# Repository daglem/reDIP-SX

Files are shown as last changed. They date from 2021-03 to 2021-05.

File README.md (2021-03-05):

# reDIP SX

## ESP32 / iCE40UP5K / SGTL5000 development board with MOS 6581/8580 SID pinout
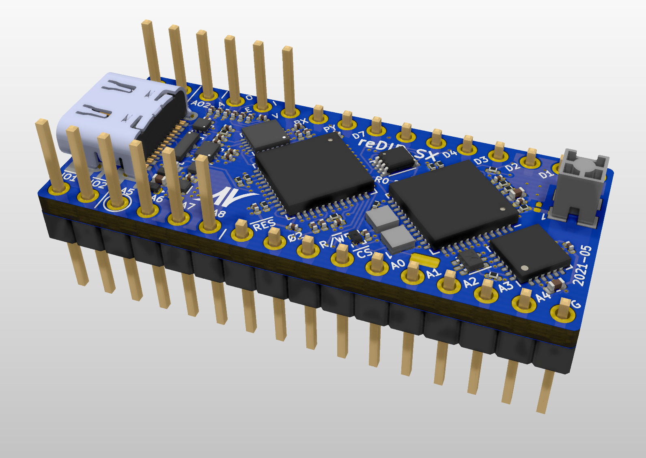
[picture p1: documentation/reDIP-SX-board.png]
Board


## Overview
The reDIP SX is an open source hardware development board which combines the following in a DIP-32 size package:

* Espressif ESP32-PICO-V3-02 MCU with Wi-Fi and Bluetooth
* Lattice iCE40UP5K FPGA
* NXP SGTL5000 Audio Codec
* 64Mbit PSRAM
* Two RGB LEDs
* USB-C receptacle for power, serial communication, and analog audio
* 5V tolerant I/O

In short, a lot of fun stuff is crammed onto a small board!

For a more purist FPGA platform for MOS 6581/8580 SID emulation, you need look no further than the [reDIP SID](https://github.com/daglem/reDIP-SID)!

## General use

### I/O interfaces

#### Header pins:

* 5V input
* 3.3V output
* 22 FPGA GPIO
* 3 FPGA current drive / open-drain I/O
* 4 audio pins (stereo line input, stereo headphone output)
* GND

All FPGA I/O is 5V tolerant, and can drive 5V TTL. JP1 can be shorted to make the 5V input pin bidirectional, e.g. to power 5V TTL devices.

The number of FPGA I/O is sufficient for e.g. three twelve-pin PMOD interfaces (with two pins open-drain or input-only).

#### Solder pads:

* Stereo line output (left, right, GND)
* RGB LED strip data
* ESP32 IO25
* ESP32 I35

#### USB-C functions:

* 5V power
* Serial interface (CP2102N to ESP32)
* Microphone input / stereo headphone output (Audio Accessory Mode)

### Internal interconnect buses

The board has three internal interconnect buses with the following ICs attached:

* SPI (Serial Peripheral Interface)
  * ESP32 MCU
  * iCE40UP5K FPGA
  * PSRAM
* I²S (Inter-IC sound)
  * ESP32 MCU
  * iCE40UP5K FPGA
  * SGTL5000 Audio Codec
* I²C (Inter-Integrated Circuit)
  * ESP32 MCU
  * iCE40UP5K FPGA
  * SGTL5000 Audio Codec

The MCU and the FPGA can communicate via the SPI bus, and they can both access the PSRAM. The FPGA is initially configured by the MCU via the SPI bus.

Both the MCU and the FPGA can act as either master or slave on the I²S bus. E.g. if the FPGA acts as the I²S master, both the audio codec and the MCU can in theory play back audio, the latter over Wi-Fi or Bluetooth.

Both the MCU and the FPGA can configure the audio codec via the I²C bus.

## MOS 6581/8580 SID compatibility

It just so happens that the board is mostly pin compatible with the venerable MOS 6581/8580 SID sound chip :wink:

For anyone wanting to experiment with a SID setup, while avoiding blown fuses, damaged sockets, and release of magic smoke:

* A 2A C64 power supply is recommended
* Make sure that JP1 is open
* Carefully follow the instructions in the [schematic diagram](documentation/reDIP-SX-sch.pdf) for making a socket adapter

## Disclaimer

Please note that this is my very first board - rookie mistakes are probably made, and [feedback](https://github.com/daglem/reDIP-SX/discussions/1) is welcome. The board has not been manufactured yet, and is thus completely untested.

## Board Front
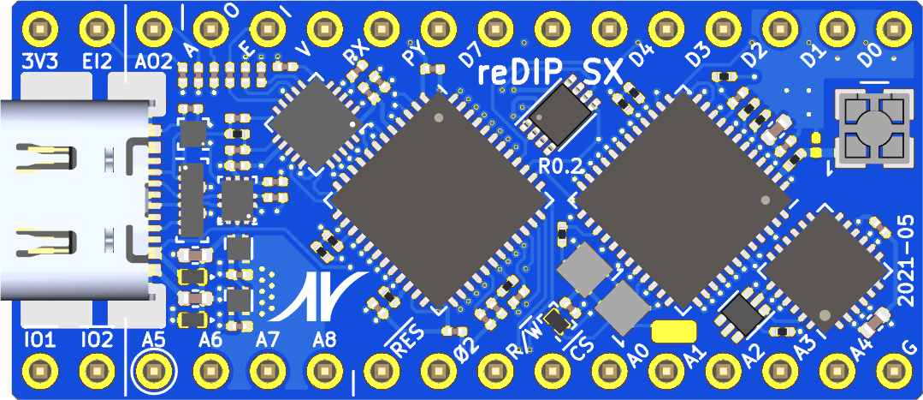
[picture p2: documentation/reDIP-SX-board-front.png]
Board Front


## Board Back
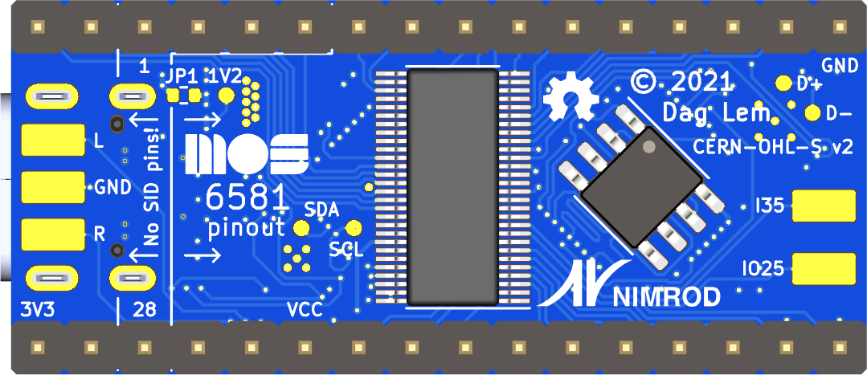
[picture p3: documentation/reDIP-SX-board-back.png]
Board Back


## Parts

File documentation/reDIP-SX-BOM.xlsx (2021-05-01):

Prj: | reDIP SX |  |  |  |  |  |  | Board Qty: | 100
Co.: | Nimrod |  |  |  |  |  |  | Unit Cost: | $0.00
Prj date: | lø. 01. mai 2021 kl. 22.55 +0200 |  |  |  |  |  |  | Total Cost: | $0.00 |  |  |  | $0.00 | 0 |  |  |  | $0.00 | 0 |  |  |  | $0.00 | 0 |  |  |  | $0.00 | 0 |  |  |  | $0.00 | 0 |  |  |  | $0.00 | 0 |  |  |  | $0.00 | 0 |  |  |  | $0.00 | 0
$ date: | 2021-05-01 22:55:19
Global Part Info |  |  |  |  |  |  |  |  |  | Arrow |  |  |  |  | Digi-Key |  |  |  |  | Farnell |  |  |  |  | LCSC |  |  |  |  | Mouser |  |  |  |  | Newark |  |  |  |  | RS Components |  |  |  |  | TME
Refs | Value | Desc | Notes | Footprint | Manf | Manf# | Qty | Unit$ | Ext$ | Avail | Purch | Unit$ | Ext$ | Cat# | Avail | Purch | Unit$ | Ext$ | Cat# | Avail | Purch | Unit$ | Ext$ | Cat# | Avail | Purch | Unit$ | Ext$ | Cat# | Avail | Purch | Unit$ | Ext$ | Cat# | Avail | Purch | Unit$ | Ext$ | Cat# | Avail | Purch | Unit$ | Ext$ | Cat# | Avail | Purch | Unit$ | Ext$ | Cat#
AE1 | 47948-0001 | ANTENNA MID CHIP |  | Molex_47948-0001 | Molex | 47948-0001 (https://www.molex.com/molex/products/part-detail/antennas/0479480001) | 0 | $0.00 | $0.00 |  |  |  |  |  | NonStk |  | $0.00 | $0.00 | WM4893CT-ND (https://octopart.com/click/track?c=1&ai=8078&sig=090b9de&sid=459&ppid=20326346&vpid=114393393&ct=offers) | 14432 |  | $0.00 | $0.00 | 3498912RL (https://octopart.com/click/track?ai=8078&sig=087403b&sid=819&ppid=20326346&vpid=632629437&ct=offers) |  |  |  |  |  | NonStk |  | $0.00 | $0.00 | 538479480001 (https://octopart.com/click/track?c=1&ai=8078&sig=0951079&sid=2401&ppid=20326346&vpid=40439801&ct=offers) | 13470 |  | $0.00 | $0.00 | 64T4821 (https://octopart.com/click/track?ai=8078&sig=0ce4145&sid=2402&ppid=20326346&vpid=503304515&ct=offers) | 8762 |  | $0.00 | $0.00 | 7595325 (https://octopart.com/click/track?ai=8078&sig=090870c&sid=10022&ppid=20326346&vpid=199068433&ct=offers) | NonStk |  | $0.00 | $0.00 | 479480001 (https://octopart.com/click/track?ai=8078&sig=0f9b69c&sid=1532&ppid=20326346&vpid=709093263&ct=offers)
C1,C3 | 1uF | CAP CER 2.2uF 16V 10% X6S 0402 | 5V DC DERATED TO 1uF | C_0402_1005Metric | Murata | GRM155C81C225KE11D (https://www.murata.com/products/productdetail.aspx?partno=GRM155C81C225KE11D) | 0 | $0.00 | $0.00 |  |  |  |  |  | NonStk |  | $0.00 | $0.00 | 490-14595-1-ND (https://octopart.com/click/track?c=1&ai=8078&sig=0de3de3&sid=459&ppid=46692789&vpid=410305221&ct=offers) | 9990 |  | $0.00 | $0.00 | 3581345 (https://octopart.com/click/track?ai=8078&sig=0d8f33b&sid=11744&ppid=46692789&vpid=667012154&ct=offers) | 3280 |  | $0.00 | $0.00 | C437523 (https://octopart.com/click/track?ai=8078&sig=005ea9f&sid=27971&ppid=46692789&vpid=666930444&ct=offers) | NonStk |  | $0.00 | $0.00 | 81GRM155C81C225KE1D (https://octopart.com/click/track?c=1&ai=8078&sig=06521e3&sid=2401&ppid=46692789&vpid=230758256&ct=offers) | 9990 |  | $0.00 | $0.00 | 92AH5000 (https://octopart.com/click/track?ai=8078&sig=0849c23&sid=2402&ppid=46692789&vpid=669036303&ct=offers)
C2,C11-C14,C18-C22,C24,C28 | 1uF | CAP CER 1uF 6.3V 20% X6S 0201 | C11-C14,C18-C22: 1.55V DC AUDIO C2,C24,C28: 1.2V DC | C_0201_0603Metric | Murata | GRM033C80J105ME05D (https://www.murata.com/products/productdetail.aspx?partno=GRM033C80J105ME05D) | 0 | $0.00 | $0.00 |  |  |  |  |  | NonStk |  | $0.00 | $0.00 | 490-13218-1-ND (https://octopart.com/click/track?c=1&ai=8078&sig=07524e2&sid=459&ppid=71220979&vpid=252726184&ct=offers) | 30000 |  | $0.00 | $0.00 | 3582762 (https://octopart.com/click/track?c=1&ai=8078&sig=013a2f0&sid=819&ppid=71220979&vpid=670691828&ct=offers) | 3440 |  | $0.00 | $0.00 | C385023 (https://octopart.com/click/track?ai=8078&sig=05d4785&sid=27971&ppid=71220979&vpid=552547217&ct=offers) |  |  |  |  |  | 30000 |  | $0.00 | $0.00 | 03AJ1531 (https://octopart.com/click/track?c=1&ai=8078&sig=0e14f17&sid=2402&ppid=71220979&vpid=671481163&ct=offers)
C4 | 1uF | CAP CER 4.7uF 6.3V 20% X5R 0201 | 3.3V DC DERATED TO 1uF | C_0201_0603Metric | Murata | GRM035R60J475ME15D (https://www.murata.com/products/productdetail.aspx?partno=GRM035R60J475ME15D) | 0 | $0.00 | $0.00 |  |  |  |  |  | 903983 |  | $0.00 | $0.00 | 490-13230-1-ND (https://octopart.com/click/track?ai=8078&sig=02d1bd9&sid=459&ppid=67141176&vpid=252726416&ct=offers) | 50000 |  | $0.00 | $0.00 | 3238402 (https://octopart.com/click/track?ai=8078&sig=087aedd&sid=11744&ppid=67141176&vpid=585909672&ct=offers) | 180195 |  | $0.00 | $0.00 | C335103 (https://octopart.com/click/track?ai=8078&sig=0ec1763&sid=27971&ppid=67141176&vpid=510777411&ct=offers) | 155342 |  | $0.00 | $0.00 | 81GRM035R60J475ME5D (https://octopart.com/click/track?ai=8078&sig=0e8e022&sid=2401&ppid=67141176&vpid=262254328&ct=offers) | 50000 |  | $0.00 | $0.00 | 34AH0743 (https://octopart.com/click/track?ai=8078&sig=02cfcbc&sid=2402&ppid=67141176&vpid=587966703&ct=offers)
C5,C17 | 10uF | CAP CER 10uF 6.3V 20% X5R 0402 | 3.3V DC | C_0402_1005Metric | Murata | GRM155R60J106ME15D (https://www.murata.com/products/productdetail.aspx?partno=GRM155R60J106ME15D) | 0 | $0.00 | $0.00 |  |  |  |  |  | 3743048 |  | $0.00 | $0.00 | 490-13238-1-ND (https://octopart.com/click/track?ai=8078&sig=018ad6b&sid=459&ppid=71220998&vpid=252726526&ct=offers) | 140000 |  | $0.00 | $0.00 | 3582794 (https://octopart.com/click/track?c=1&ai=8078&sig=0115312&sid=819&ppid=71220998&vpid=670691894&ct=offers) | 2990 |  | $0.00 | $0.00 | C412251 (https://octopart.com/click/track?ai=8078&sig=0543bf4&sid=27971&ppid=71220998&vpid=582946846&ct=offers) | 1634310 |  | $0.00 | $0.00 | 81GRM155R60J106ME5D (https://octopart.com/click/track?ai=8078&sig=0b273d0&sid=2401&ppid=71220998&vpid=259388278&ct=offers) | 150000 |  | $0.00 | $0.00 | 03AJ1576 (https://octopart.com/click/track?c=1&ai=8078&sig=0c372ee&sid=2402&ppid=71220998&vpid=671481195&ct=offers)
C6-C10,C15,C16,C23,C25-C27,C29-C32 | 0.1uF | CAP CER 0.22uF 6.3V 20% X5R 0201 | C6-C9,C16,C23,C25-C27,C29-C32: 3.3V DC DERATED TO 0.1uF C10,C15: 1.55V DC AUDIO DERATED TO 0.1uF | C_0201_0603Metric | Murata | GRM033R60J224KE15D (https://www.murata.com/products/productdetail.aspx?partno=GRM033R60J224KE15D) | 0 | $0.00 | $0.00 |  |  |  |  |  | 2181765 |  | $0.00 | $0.00 | 490-10406-1-ND (https://octopart.com/click/track?ai=8078&sig=0492ec2&sid=459&ppid=51454422&vpid=172161550&ct=offers) | 120000 |  | $0.00 | $0.00 | 2990684 (https://octopart.com/click/track?ai=8078&sig=0efc20f&sid=819&ppid=51454422&vpid=528007216&ct=offers) | 20800 |  | $0.00 | $0.00 | C76931 (https://octopart.com/click/track?ai=8078&sig=0f2788c&sid=27971&ppid=51454422&vpid=445986847&ct=offers) | 301000 |  | $0.00 | $0.00 | 81GRM33R60J224KE15D (https://octopart.com/click/track?ai=8078&sig=0207666&sid=2401&ppid=51454422&vpid=178169497&ct=offers) | 120000 |  | $0.00 | $0.00 | 94AC8892 (https://octopart.com/click/track?ai=8078&sig=0d37eed&sid=2402&ppid=51454422&vpid=529126546&ct=offers) | 7000 |  | $0.00 | $0.00 | 1851581 (https://octopart.com/click/track?ai=8078&sig=0eaea66&sid=10022&ppid=51454422&vpid=562632808&ct=offers)
D1,D2 | PMEG2010BELD | DIODE SCHOTTKY 20V 1A LOW VF SOD882D |  | D_SOD-882D | Nexperia | PMEG2010BELD,315 (https://assets.nexperia.com/documents/data-sheet/PMEG2010BELD.pdf) | 0 | $0.00 | $0.00 |  |  |  |  |  | 32181 |  | $0.00 | $0.00 | 1727-1084-1-ND (https://octopart.com/click/track?ai=8078&sig=05f022d&sid=459&ppid=78741408&vpid=417205872&ct=offers) | NonStk |  | $0.00 | $0.00 | 2191801 (https://octopart.com/click/track?c=1&ai=8078&sig=0ee080b&sid=819&ppid=78741408&vpid=521253387&ct=offers) |  |  |  |  |  | 249 |  | $0.00 | $0.00 | 771PMEG2010BELD,315 (https://octopart.com/click/track?ai=8078&sig=077655c&sid=2401&ppid=78741408&vpid=416182007&ct=offers) | NonStk |  | $0.00 | $0.00 | 55W4407 (https://octopart.com/click/track?c=1&ai=8078&sig=03a6e2e&sid=2402&ppid=78741408&vpid=511382518&ct=offers)
D3 | ESD7016 | IC ESD PROTECTION UDFN-8 |  | 517CB-3.3x1.0mm_P0.4mm | ON Semiconductor | ESD7016MUTAG (https://www.onsemi.com/pub/Collateral/ESD7016-D.PDF) | 0 | $0.00 | $0.00 |  |  |  |  |  | 23415 |  | $0.00 | $0.00 | ESD7016MUTAGOSCT-ND (https://octopart.com/click/track?ai=8078&sig=0f2b3ec&sid=459&ppid=25645602&vpid=210238806&ct=offers) | 10184 |  | $0.00 | $0.00 | 2535917 (https://octopart.com/click/track?ai=8078&sig=01a9746&sid=11744&ppid=25645602&vpid=260636544&ct=offers) | 3073 |  | $0.00 | $0.00 | C463227 (https://octopart.com/click/track?ai=8078&sig=0d3fc6a&sid=27971&ppid=25645602&vpid=609441157&ct=offers) | 631 |  | $0.00 | $0.00 | 863ESD7016MUTAG (https://octopart.com/click/track?ai=8078&sig=0b9599e&sid=2401&ppid=25645602&vpid=93676548&ct=offers) | 442 |  | $0.00 | $0.00 | 82Y9140 (https://octopart.com/click/track?ai=8078&sig=0a93035&sid=2402&ppid=25645602&vpid=261509788&ct=offers) | 2450 |  | $0.00 | $0.00 | 8829708 (https://octopart.com/click/track?ai=8078&sig=0d534f4&sid=10022&ppid=25645602&vpid=229322189&ct=offers)
D4,D5 | SMD-LX0707RGB-TR | IC LED RGB 0707 | REPLACEMENT PARTS: Everlight 19-C47/RSGHBHC-5V01/2T, Everlight EAST1818RGBICA0 | SMD-LX0707RGB-TR | Lumex | SMD-LX0707RGB-TR (https://www.lumex.com/spec/SMD-LX0707RGB-TR.pdf) | 0 | $0.00 | $0.00 |  |  |  |  |  | 24663 |  | $0.00 | $0.00 | 67-2331-1-ND (https://octopart.com/click/track?ai=8078&sig=011841b&sid=459&ppid=98770141&vpid=527582517&ct=offers) | NonStk |  | $0.00 | $0.00 | 3216559 (https://octopart.com/click/track?c=1&ai=8078&sig=08846a9&sid=819&ppid=98770141&vpid=575179783&ct=offers) |  |  |  |  |  | 28018 |  | $0.00 | $0.00 | 696SMDLX0707RGBTR (https://octopart.com/click/track?ai=8078&sig=01b9309&sid=2401&ppid=98770141&vpid=527691918&ct=offers) | NonStk |  | $0.00 | $0.00 | 02AH5948 (https://octopart.com/click/track?c=1&ai=8078&sig=0c78da6&sid=2402&ppid=98770141&vpid=547451562&ct=offers) |  |  |  |  |  | 1979 |  | $0.00 | $0.00 | SMDLX0707RGBTR (https://octopart.com/click/track?ai=8078&sig=0f2b5ee&sid=1532&ppid=98770141&vpid=709065371&ct=offers)
J1 | DX07S016JA1 | CONN USB-C | PIN-IN-PASTE, paste overprinting included in design | USB_C_Receptacle_JAE_DX07S016JA1 | Japan Aviation Electronics Industry, Ltd. | DX07S016JA1R1500 (https://www.jae.com/en/connectors/series/detail/product/id=91780) | 0 | $0.00 | $0.00 |  |  |  |  |  | NonStk |  | $0.00 | $0.00 | 670-DX07S016JA1R1500CT-ND (https://octopart.com/click/track?c=1&ai=8078&sig=081d65f&sid=459&ppid=106944056&vpid=605161093&ct=offers) |  |  |  |  |  |  |  |  |  |  | NonStk |  | $0.00 | $0.00 | 656DX07S016JA1R1500 (https://octopart.com/click/track?c=1&ai=8078&sig=0443fa1&sid=2401&ppid=106944056&vpid=605115352&ct=offers) |  |  |  |  |  | 78 |  | $0.00 | $0.00 | 2017049 (https://octopart.com/click/track?ai=8078&sig=0e2ae8f&sid=10022&ppid=106944056&vpid=654522308&ct=offers)
J5,J6 | Conn_01x06 | CONN HEADER 6 POS .100" SGL GOLD MATING 5.84mm TAIL 8.13mm |  | PinHeader_1x06_P2.54mm_Vertical_LongTail | Sullins | PRPC006SACN-RC (https://drawings-pdf.s3.amazonaws.com/11635.pdf) | 0 | $0.00 | $0.00 |  |  |  |  |  | 890 |  | $0.00 | $0.00 | S1131EC-06-ND (https://octopart.com/click/track?c=1&ai=8078&sig=01af8bd&sid=459&ppid=22265644&vpid=47550630&ct=offers)
J7,J8 | Conn_01x10 | CONN HEADER 10 POS .100" SGL GOLD MATING 5.84mm TAIL 3.05mm |  | PinHeader_1x10_P2.54mm_Vertical | Sullins | PRPC010SAAN-RC (https://drawings-pdf.s3.amazonaws.com/11635.pdf) | 0 | $0.00 | $0.00 |  |  |  |  |  | 3902 |  | $0.00 | $0.00 | S1011EC-10-ND (https://octopart.com/click/track?c=1&ai=8078&sig=02f1022&sid=459&ppid=22265699&vpid=47550685&ct=offers)
Q1 | PEMH4 | TRANSISTOR NPN/NPN RET R1=10kΩ R2=open SOT666 |  | SOT-666 | Nexperia | PEMH4,115 (https://assets.nexperia.com/documents/data-sheet/PEMH4_PUMH4.pdf) | 0 | $0.00 | $0.00 |  |  |  |  |  | NonStk |  | $0.00 | $0.00 | PEMH4,115-ND (https://octopart.com/click/track?c=1&ai=8078&sig=0a777c0&sid=459&ppid=78754818&vpid=413679980&ct=offers) | NonStk |  | $0.00 | $0.00 | 1758021 (https://octopart.com/click/track?c=1&ai=8078&sig=05dcde8&sid=819&ppid=78754818&vpid=414861426&ct=offers) |  |  |  |  |  | 2579 |  | $0.00 | $0.00 | 771PEMH4115 (https://octopart.com/click/track?ai=8078&sig=023faf4&sid=2401&ppid=78754818&vpid=416181661&ct=offers) | NonStk |  | $0.00 | $0.00 | 34R4491 (https://octopart.com/click/track?c=1&ai=8078&sig=0cc952a&sid=2402&ppid=78754818&vpid=598286280&ct=offers) |  |  |  |  |  | NonStk |  | $0.00 | $0.00 | PEMH4.115 (https://octopart.com/click/track?ai=8078&sig=07f86d6&sid=1532&ppid=78754818&vpid=709102645&ct=offers)
Q2 | PDTA143ZMB | TRANSISTOR PNP RET R1=4.7kΩ R2=47kΩ 100mA SOT883B |  | SOT-883 | Nexperia | PDTA143ZMB,315 (https://assets.nexperia.com/documents/data-sheet/PDTA143ZMB.pdf) | 0 | $0.00 | $0.00 |  |  |  |  |  | NonStk |  | $0.00 | $0.00 | PDTA143ZMB,315-ND (https://octopart.com/click/track?c=1&ai=8078&sig=0944463&sid=459&ppid=78754604&vpid=413679736&ct=offers) |  |  |  |  |  |  |  |  |  |  | 10000 |  | $0.00 | $0.00 | 771PDTA143ZMB315 (https://octopart.com/click/track?ai=8078&sig=0d6ccfc&sid=2401&ppid=78754604&vpid=504003500&ct=offers)
R1,R6 | 0 | RES 0Ω 50mW 1% 0201 |  | R_0201_0603Metric | Panasonic | ERJ-1GN0R00C (https://b2b-api.panasonic.eu/file_stream/pids/fileversion/1242) | 0 | $0.00 | $0.00 |  |  |  |  |  | 4340071 |  | $0.00 | $0.00 | P15979CT-ND (https://octopart.com/click/track?ai=8078&sig=06e3983&sid=459&ppid=16432844&vpid=73994004&ct=offers) | 95971 |  | $0.00 | $0.00 | 2799511 (https://octopart.com/click/track?c=1&ai=8078&sig=0993eba&sid=11744&ppid=16432844&vpid=709673718&ct=offers) |  |  |  |  |  | 894751 |  | $0.00 | $0.00 | 667ERJ1GN0R00C (https://octopart.com/click/track?ai=8078&sig=06ab724&sid=2401&ppid=16432844&vpid=41840075&ct=offers) | 95971 |  | $0.00 | $0.00 | 51W5934 (https://octopart.com/click/track?ai=8078&sig=03714c0&sid=2402&ppid=16432844&vpid=87993748&ct=offers) | 1038637 |  | $0.00 | $0.00 | 1755716 (https://octopart.com/click/track?ai=8078&sig=03492ea&sid=10022&ppid=16432844&vpid=501237966&ct=offers)
R13 | 22 | RES 22Ω 50mW 5% 0201 |  | R_0201_0603Metric | Panasonic | ERJ-1GNJ220C (https://b2b-api.panasonic.eu/file_stream/pids/fileversion/1242) | 0 | $0.00 | $0.00 |  |  |  |  |  | NonStk |  | $0.00 | $0.00 | P123275CT-ND (https://octopart.com/click/track?c=1&ai=8078&sig=04cd504&sid=459&ppid=42505965&vpid=465235288&ct=offers) | NonStk |  | $0.00 | $0.00 | 3303209 (https://octopart.com/click/track?c=1&ai=8078&sig=0433a1d&sid=819&ppid=42505965&vpid=603690885&ct=offers) |  |  |  |  |  | 11274 |  | $0.00 | $0.00 | 667ERJ1GNJ220C (https://octopart.com/click/track?ai=8078&sig=0d716f6&sid=2401&ppid=42505965&vpid=165486571&ct=offers) | NonStk |  | $0.00 | $0.00 | 51W5825 (https://octopart.com/click/track?c=1&ai=8078&sig=0965e6c&sid=2402&ppid=42505965&vpid=524371516&ct=offers)
R2,R3,R5 | 2.2k | RES 2.2kΩ 50mW 5% 0201 |  | R_0201_0603Metric | Panasonic | ERJ-1GNJ222C (https://b2b-api.panasonic.eu/file_stream/pids/fileversion/1242) | 0 | $0.00 | $0.00 |  |  |  |  |  | NonStk |  | $0.00 | $0.00 | P123277CT-ND (https://octopart.com/click/track?c=1&ai=8078&sig=0d2c7b0&sid=459&ppid=44403350&vpid=465235292&ct=offers) | NonStk |  | $0.00 | $0.00 | 3303211 (https://octopart.com/click/track?c=1&ai=8078&sig=098df08&sid=819&ppid=44403350&vpid=603690887&ct=offers) |  |  |  |  |  | 13882 |  | $0.00 | $0.00 | 667ERJ1GNJ222C (https://octopart.com/click/track?ai=8078&sig=07d1d1b&sid=2401&ppid=44403350&vpid=248150297&ct=offers) | NonStk |  | $0.00 | $0.00 | 51W5827 (https://octopart.com/click/track?c=1&ai=8078&sig=01bc52e&sid=2402&ppid=44403350&vpid=632042349&ct=offers) | 38000 |  | $0.00 | $0.00 | 1797111 (https://octopart.com/click/track?ai=8078&sig=07954d2&sid=10022&ppid=44403350&vpid=527534079&ct=offers)
R4,R10,R11 | 10k | RES 10kΩ 50mW 5% 0201 |  | R_0201_0603Metric | Panasonic | ERJ-1GNJ103C (https://b2b-api.panasonic.eu/file_stream/pids/fileversion/1242) | 0 | $0.00 | $0.00 |  |  |  |  |  | 491082 |  | $0.00 | $0.00 | P123222CT-ND (https://octopart.com/click/track?ai=8078&sig=0301d78&sid=459&ppid=44322539&vpid=465235182&ct=offers) | NonStk |  | $0.00 | $0.00 | 3303150 (https://octopart.com/click/track?c=1&ai=8078&sig=0fd9335&sid=819&ppid=44322539&vpid=603690832&ct=offers) | 4000 |  | $0.00 | $0.00 | C242159 (https://octopart.com/click/track?ai=8078&sig=06c973b&sid=27971&ppid=44322539&vpid=495511688&ct=offers) | 80383 |  | $0.00 | $0.00 | 667ERJ1GNJ103C (https://octopart.com/click/track?ai=8078&sig=0a64394&sid=2401&ppid=44322539&vpid=120580014&ct=offers) | NonStk |  | $0.00 | $0.00 | 23AC4811 (https://octopart.com/click/track?c=1&ai=8078&sig=07aa8d7&sid=2402&ppid=44322539&vpid=477474193&ct=offers) | 8000 |  | $0.00 | $0.00 | 1797103 (https://octopart.com/click/track?ai=8078&sig=0dcb783&sid=10022&ppid=44322539&vpid=527534071&ct=offers)
R7,R8 | 5.1k | RES 5.1kΩ 50mW 5% 0201 |  | R_0201_0603Metric | Panasonic | ERJ-1GNJ512C (https://b2b-api.panasonic.eu/file_stream/pids/fileversion/1242) | 0 | $0.00 | $0.00 |  |  |  |  |  | 70771 |  | $0.00 | $0.00 | P123340CT-ND (https://octopart.com/click/track?ai=8078&sig=0dd36dc&sid=459&ppid=66942597&vpid=465235418&ct=offers) | NonStk |  | $0.00 | $0.00 | 3303281 (https://octopart.com/click/track?c=1&ai=8078&sig=01b939b&sid=819&ppid=66942597&vpid=603690950&ct=offers) |  |  |  |  |  | 80525 |  | $0.00 | $0.00 | 667ERJ1GNJ512C (https://octopart.com/click/track?ai=8078&sig=07a33f5&sid=2401&ppid=66942597&vpid=265943161&ct=offers) | NonStk |  |  |  | 51W5889 (https://octopart.com/click/track?c=1&ai=8078&sig=0cb0675&sid=2402&ppid=66942597&vpid=669843420&ct=offers)
R9,R12 | 100 | RES 100Ω 50mW 5% 0201 |  | R_0201_0603Metric | Panasonic | ERJ-1GNJ101C (https://b2b-api.panasonic.eu/file_stream/pids/fileversion/1242) | 0 | $0.00 | $0.00 |  |  |  |  |  | 13201 |  | $0.00 | $0.00 | P123220CT-ND (https://octopart.com/click/track?ai=8078&sig=080fecf&sid=459&ppid=44403300&vpid=465235178&ct=offers) | NonStk |  | $0.00 | $0.00 | 3303148 (https://octopart.com/click/track?c=1&ai=8078&sig=0b30f5a&sid=819&ppid=44403300&vpid=603690830&ct=offers) | 14800 |  | $0.00 | $0.00 | C713500 (https://octopart.com/click/track?ai=8078&sig=08d00b1&sid=27971&ppid=44403300&vpid=669037577&ct=offers) | 87234 |  | $0.00 | $0.00 | 667ERJ1GNJ101C (https://octopart.com/click/track?ai=8078&sig=0e9f721&sid=2401&ppid=44403300&vpid=165486549&ct=offers) | NonStk |  |  |  | 51W5773 (https://octopart.com/click/track?c=1&ai=8078&sig=0f3777c&sid=2402&ppid=44403300&vpid=166626673&ct=offers) | 37000 |  | $0.00 | $0.00 | 1797101 (https://octopart.com/click/track?ai=8078&sig=05f26cb&sid=10022&ppid=44403300&vpid=527534069&ct=offers)
U1 | NCP115AMX120TCG | IC REG LDO 1.2V 300mA XDFN4 |  | CASE_711AJ_1.0x1.0mm_P0.65mm | ON Semiconductor | NCP115AMX120TCG (https://www.onsemi.com/pdf/datasheet/ncp115-d.pdf) | 0 | $0.00 | $0.00 |  |  |  |  |  | 1191 |  | $0.00 | $0.00 | NCP115AMX120TCGOSCT-ND (https://octopart.com/click/track?ai=8078&sig=0a3f4b6&sid=459&ppid=92380524&vpid=530205177&ct=offers) | 1973 |  | $0.00 | $0.00 | 3010452 (https://octopart.com/click/track?ai=8078&sig=0e69391&sid=11744&ppid=92380524&vpid=531143297&ct=offers) |  |  |  |  |  | 13244 |  | $0.00 | $0.00 | 863NCP115AMX120TCG (https://octopart.com/click/track?ai=8078&sig=036a8af&sid=2401&ppid=92380524&vpid=523401631&ct=offers) | 1948 |  | $0.00 | $0.00 | 97AC7838 (https://octopart.com/click/track?ai=8078&sig=09fcc50&sid=2402&ppid=92380524&vpid=531928826&ct=offers) | 3000 |  | $0.00 | $0.00 | 1861230 (https://octopart.com/click/track?ai=8078&sig=0259cbd&sid=10022&ppid=92380524&vpid=562641106&ct=offers)
U10 | SN74CBTD16211DGVR | IC BUS SWITCH WITH LEVEL SHIFTER TVSOP-56 |  | Texas_TVSOP-56_4.4x11.3mm_P0.4mm | TI | SN74CBTD16211DGVR (https://www.ti.com/lit/ds/symlink/sn74cbtd16211.pdf) | 0 | $0.00 | $0.00 |  |  |  |  |  | NonStk |  | $0.00 | $0.00 | 296-6475-2-ND (https://octopart.com/click/track?c=1&ai=8078&sig=0aac5c3&sid=459&ppid=472676&vpid=1588405&ct=offers) |  |  |  |  |  | 1990 |  | $0.00 | $0.00 | C2683750 (https://octopart.com/click/track?ai=8078&sig=0221cb4&sid=27971&ppid=472676&vpid=696942338&ct=offers) | 594 |  | $0.00 | $0.00 | 59574CBTD16211DGVR (https://octopart.com/click/track?ai=8078&sig=0681b00&sid=2401&ppid=472676&vpid=46887142&ct=offers)
U11 | 7WBD3306USG | IC BUS SWITCH WITH LEVEL SHIFTER US8 |  | CASE_493-8_2.3x2mm_P0.5mm | ON Semiconductor | 7WBD3306USG (https://www.onsemi.com/pdf/datasheet/7wbd3306-d.pdf) | 0 | $0.00 | $0.00 |  |  |  |  |  | 8864 |  | $0.00 | $0.00 | 7WBD3306USGOSCT-ND (https://octopart.com/click/track?ai=8078&sig=0d1d92d&sid=459&ppid=18611571&vpid=479898797&ct=offers) | 2706 |  | $0.00 | $0.00 | 2728387 (https://octopart.com/click/track?ai=8078&sig=01a6fba&sid=819&ppid=18611571&vpid=424087899&ct=offers) |  |  |  |  |  | 2522 |  | $0.00 | $0.00 | 8637WBD3306USG (https://octopart.com/click/track?ai=8078&sig=0bb0cd7&sid=2401&ppid=18611571&vpid=37811243&ct=offers) | 2706 |  | $0.00 | $0.00 | 14AC5540 (https://octopart.com/click/track?ai=8078&sig=096dade&sid=2402&ppid=18611571&vpid=423912636&ct=offers) | 100 |  | $0.00 | $0.00 | 8009402 (https://octopart.com/click/track?ai=8078&sig=06459c7&sid=10022&ppid=18611571&vpid=199083405&ct=offers) | NonStk |  | $0.00 | $0.00 | 7WBD3306USG (https://octopart.com/click/track?ai=8078&sig=0f582d1&sid=1532&ppid=18611571&vpid=709118430&ct=offers)
U2 | NCP167AMX330TBG | IC REG LDO 3.3V 700mA XDFN4 |  | CASE_711AJ_1.0x1.0mm_P0.65mm | ON Semiconductor | NCP167AMX330TBG (https://www.onsemi.com/pub/Collateral/NCP167-D.PDF) | 0 | $0.00 | $0.00 |  |  |  |  |  | 2741 |  | $0.00 | $0.00 | NCP167AMX330TBGOSCT-ND (https://octopart.com/click/track?ai=8078&sig=08df17c&sid=459&ppid=85869721&vpid=510801591&ct=offers) | 215 |  | $0.00 | $0.00 | 2981158 (https://octopart.com/click/track?ai=8078&sig=03da2a6&sid=11744&ppid=85869721&vpid=511860082&ct=offers) |  |  |  |  |  | 8389 |  | $0.00 | $0.00 | 863NCP167AMX330TBG (https://octopart.com/click/track?ai=8078&sig=093fed6&sid=2401&ppid=85869721&vpid=480971673&ct=offers) | 190 |  | $0.00 | $0.00 | 84AC7230 (https://octopart.com/click/track?ai=8078&sig=061a238&sid=2402&ppid=85869721&vpid=530859240&ct=offers) | 12 |  | $0.00 | $0.00 | 1858072 (https://octopart.com/click/track?ai=8078&sig=004d31c&sid=10022&ppid=85869721&vpid=562641329&ct=offers)
U3 | FSA221UMX | IC USB AUDIO SWITCH UQFN-10 |  | CASE_523BC_1.4x1.8_P0.4mm | ON Semiconductor | FSA221UMX (https://www.onsemi.com/pub/Collateral/FSA221-D.pdf) | 0 | $0.00 | $0.00 |  |  |  |  |  | NonStk |  | $0.00 | $0.00 | FSA221UMXTR-ND (https://octopart.com/click/track?c=1&ai=8078&sig=0bf5e3c&sid=459&ppid=84328203&vpid=452466845&ct=offers) | NonStk |  | $0.00 | $0.00 | 3614346 (https://octopart.com/click/track?c=1&ai=8078&sig=0651f87&sid=819&ppid=84328203&vpid=679564055&ct=offers) |  |  |  |  |  | 3515 |  | $0.00 | $0.00 | 512FSA221UMX (https://octopart.com/click/track?ai=8078&sig=07ee363&sid=2401&ppid=84328203&vpid=438583992&ct=offers)
U4 | SGTL5000XNLA3 | IC AUDIO CODEC UQFN-20 | ALTERNATIVE PART #: SGTL5000XNLA3R2 | QFN-20-1EP_3x3mm_P0.4mm_EP1.65x1.65mm | NXP | SGTL5000XNLA3 (https://www.nxp.com/docs/en/data-sheet/SGTL5000.pdf) | 0 | $0.00 | $0.00 |  |  |  |  |  | NonStk |  | $0.00 | $0.00 | SGTL5000XNLA3-ND (https://octopart.com/click/track?c=1&ai=8078&sig=0e67bb5&sid=459&ppid=70302733&vpid=248305906&ct=offers) | NonStk |  | $0.00 | $0.00 | 2308050 (https://octopart.com/click/track?c=1&ai=8078&sig=0d698c2&sid=11744&ppid=70302733&vpid=247788338&ct=offers) |  |  |  |  |  | NonStk |  | $0.00 | $0.00 | 841SGTL5000XNLA3 (https://octopart.com/click/track?c=1&ai=8078&sig=047f522&sid=2401&ppid=70302733&vpid=251555959&ct=offers) | NonStk |  | $0.00 | $0.00 | 14R9111 (https://octopart.com/click/track?c=1&ai=8078&sig=00417c4&sid=2402&ppid=70302733&vpid=270421497&ct=offers)
U5 | ESP32-PICO-V3-02 | IC MCU WIFI BLUETOOTH SIP QFN-48 |  | QFN-48-1EP_7x7mm_P0.5mm_EP5.3x5.3mm | Espressif | ESP32-PICO-V3-02 (https://www.espressif.com/sites/default/files/documentation/esp32-pico-v3-02_datasheet_en.pdf) | 0 | $0.00 | $0.00 |  |  |  |  |  | 280 |  | $0.00 | $0.00 | 1965-ESP32-PICO-V3-02-ND (https://octopart.com/click/track?c=1&ai=8078&sig=02cf195&sid=459&ppid=112268551&vpid=658695230&ct=offers) |  |  |  |  |  |  |  |  |  |  | NonStk |  | $0.00 | $0.00 | 356ESP32PICOV302 (https://octopart.com/click/track?c=1&ai=8078&sig=05078e7&sid=2401&ppid=112268551&vpid=659792027&ct=offers) |  |  |  |  |  |  |  |  |  |  | NonStk |  | $0.00 | $0.00 | ESP32PICOV302 (https://octopart.com/click/track?ai=8078&sig=049505d&sid=1532&ppid=112268551&vpid=707882674&ct=offers)
U6 | CP2102N-A02-GQFN24 | IC USB TO UART BRIDGE QFN-24 |  | QFN-24-1EP_4x4mm_P0.5mm_EP2.6x2.6mm | SiLabs | CP2102N-A02-GQFN24R (https://www.silabs.com/documents/public/data-sheets/cp2102n-datasheet.pdf) | 0 | $0.00 | $0.00 |  |  |  |  |  | NonStk |  | $0.00 | $0.00 | 336-5888-1-ND (https://octopart.com/click/track?c=1&ai=8078&sig=0ea183e&sid=459&ppid=99772192&vpid=533329931&ct=offers) | NonStk |  | $0.00 | $0.00 | 3387002 (https://octopart.com/click/track?c=1&ai=8078&sig=07a36f0&sid=819&ppid=99772192&vpid=614426008&ct=offers) |  |  |  |  |  | NonStk |  | $0.00 | $0.00 | 634CP2102NA02QFN24R (https://octopart.com/click/track?c=1&ai=8078&sig=08e6d81&sid=2401&ppid=99772192&vpid=534001944&ct=offers) | NonStk |  | $0.00 | $0.00 | 66AH5403 (https://octopart.com/click/track?c=1&ai=8078&sig=00399cc&sid=2402&ppid=99772192&vpid=614834886&ct=offers)
U7 | FSA8049UCX | IC AUDIO JACK DETECTION SWITCH WLCSP-9 |  | WLCSP-9_1.16x1.16mm_Layout3x3_P0.4mm | ON Semiconductor | FSA8049UCX (https://www.onsemi.com/pub/Collateral/FSA8049-D.pdf) | 0 | $0.00 | $0.00 |  |  |  |  |  | 6488 |  | $0.00 | $0.00 | FSA8049UCXFSCT-ND (https://octopart.com/click/track?ai=8078&sig=04f3049&sid=459&ppid=84328290&vpid=452467072&ct=offers) | NonStk |  |  |  | 2100417 (https://octopart.com/click/track?c=1&ai=8078&sig=0bddf8a&sid=11744&ppid=84328290&vpid=440102216&ct=offers) | 2781 |  | $0.00 | $0.00 | C128378 (https://octopart.com/click/track?ai=8078&sig=04c986a&sid=27971&ppid=84328290&vpid=476993210&ct=offers) | 5089 |  | $0.00 | $0.00 | 512FSA8049UCX (https://octopart.com/click/track?ai=8078&sig=0683f8d&sid=2401&ppid=84328290&vpid=438584064&ct=offers) | NonStk |  | $0.00 | $0.00 | 95T0140 (https://octopart.com/click/track?c=1&ai=8078&sig=08b34e2&sid=2402&ppid=84328290&vpid=518569690&ct=offers)
U8 | ICE40UP5K-SG48I | IC FPGA QFN-48 |  | QFN-48-1EP_7x7mm_P0.5mm_EP5.6x5.6mm | Lattice | ICE40UP5K-SG48I (http://www.latticesemi.com/Products/FPGAandCPLD/iCE40UltraPlus) | 0 | $0.00 | $0.00 |  |  |  |  |  | 333 |  | $0.00 | $0.00 | 220-2212-1-ND (https://octopart.com/click/track?c=1&ai=8078&sig=08e94d1&sid=459&ppid=87369311&vpid=495120370&ct=offers) |  |  |  |  |  |  |  |  |  |  | 2559 |  | $0.00 | $0.00 | 842ICE40UP5KSG48I (https://octopart.com/click/track?ai=8078&sig=00e2810&sid=2401&ppid=87369311&vpid=477152809&ct=offers)
U9 | APS6404L-3SQR-SN | IC PSRAM 8MB SOP-8 | REPLACEMENT PARTS: Lyontek LY68L6400SLIT, Espressif ESP-PSRAM64H, IPUS IPS6404L-SQ | SOP-8_3.9x4.9mm_P1.27mm | AP Memory | APS6404L-3SQR-SN (https://www.apmemory.com/wp-content/uploads/APM_PSRAM_QSPI-APS6404L-3SQR-v2.3-PKG.pdf) | 0 | $0.00 | $0.00
 | Used currency rates: |  |  |  |  |  |  | Total Purchase: | $0.00 | Buy here (https://www.arrow.com/en/bom-tool/) | 0 |  | $0.00 |  | Buy here (https://www.digikey.com/ordering/shoppingcart) | 0 |  | $0.00 |  | Buy here (https://www.newark.com/quick-order?isQuickPaste=true) | 0 |  | $0.00 |  | Buy here (https://lcsc.com/bom.html) | 0 |  | $0.00 |  | Buy here (https://mouser.com/bom/) | 0 |  | $0.00 |  | Buy here (https://www.newark.com/quick-order?isQuickPaste=true) | 0 |  | $0.00 |  | Buy here (https://uk.rs-online.com/web/mylists/manualQuotes.html?method=showEnquiryCreationPage&mode=new) | 0 |  | $0.00 |  | Buy here (https://www.tme.eu/en/Profile/QuickBuy/load.html) | 0 |  | $0.00
 | USD($)/GBP(£): | 1.293904701 |  |  |  |  |  | Purchase description: |  |  | 0 |  |  |  |  | 0 |  |  |  |  | 0 |  |  |  |  | 0 |  |  |  |  | 0 |  |  |  |  | 0 |  |  |  |  | 0 |  |  |  |  | 0
 |  |  |  |  |  |  |  |  |  |  | 0 |  |  |  |  | 0 |  |  |  |  | 0 |  |  |  |  | 0 |  |  |  |  | 0 |  |  |  |  | 0 |  |  |  |  | 0 |  |  |  |  | 0
KiCost® v.1.1.5 |  |  |  |  |  |  |  |  |  |  | 0 |  |  |  |  | 0 |  |  |  |  | 0 |  |  |  |  | 0 |  |  |  |  | 0 |  |  |  |  | 0 |  |  |  |  | 0 |  |  |  |  | 0
 |  |  |  |  |  |  |  |  |  |  | 0 |  |  |  |  | 0 |  |  |  |  | 0 |  |  |  |  | 0 |  |  |  |  | 0 |  |  |  |  | 0 |  |  |  |  | 0 |  |  |  |  | 0
 |  |  |  |  |  |  |  |  |  |  | 0 |  |  |  |  | 0 |  |  |  |  | 0 |  |  |  |  | 0 |  |  |  |  | 0 |  |  |  |  | 0 |  |  |  |  | 0 |  |  |  |  | 0
 |  |  |  |  |  |  |  |  |  |  | 0 |  |  |  |  | 0 |  |  |  |  | 0 |  |  |  |  | 0 |  |  |  |  | 0 |  |  |  |  | 0 |  |  |  |  | 0 |  |  |  |  | 0
 |  |  |  |  |  |  |  |  |  |  | 0 |  |  |  |  | 0 |  |  |  |  | 0 |  |  |  |  | 0 |  |  |  |  | 0 |  |  |  |  | 0 |  |  |  |  | 0 |  |  |  |  | 0
 |  |  |  |  |  |  |  |  |  |  | 0 |  |  |  |  | 0 |  |  |  |  | 0 |  |  |  |  | 0 |  |  |  |  | 0 |  |  |  |  | 0 |  |  |  |  | 0 |  |  |  |  | 0
 |  |  |  |  |  |  |  |  |  |  | 0 |  |  |  |  | 0 |  |  |  |  | 0 |  |  |  |  | 0 |  |  |  |  | 0 |  |  |  |  | 0 |  |  |  |  | 0 |  |  |  |  | 0
 |  |  |  |  |  |  |  |  |  |  | 0 |  |  |  |  | 0 |  |  |  |  | 0 |  |  |  |  | 0 |  |  |  |  | 0 |  |  |  |  | 0 |  |  |  |  | 0 |  |  |  |  | 0
 |  |  |  |  |  |  |  |  |  |  | 0 |  |  |  |  | 0 |  |  |  |  | 0 |  |  |  |  | 0 |  |  |  |  | 0 |  |  |  |  | 0 |  |  |  |  | 0 |  |  |  |  | 0
 |  |  |  |  |  |  |  |  |  |  | 0 |  |  |  |  | 0 |  |  |  |  | 0 |  |  |  |  | 0 |  |  |  |  | 0 |  |  |  |  | 0 |  |  |  |  | 0 |  |  |  |  | 0
 |  |  |  |  |  |  |  |  |  |  | 0 |  |  |  |  | 0 |  |  |  |  | 0 |  |  |  |  | 0 |  |  |  |  | 0 |  |  |  |  | 0 |  |  |  |  | 0 |  |  |  |  | 0
 |  |  |  |  |  |  |  |  |  |  | 0 |  |  |  |  | 0 |  |  |  |  | 0 |  |  |  |  | 0 |  |  |  |  | 0 |  |  |  |  | 0 |  |  |  |  | 0 |  |  |  |  | 0
 |  |  |  |  |  |  |  |  |  |  | 0 |  |  |  |  | 0 |  |  |  |  | 0 |  |  |  |  | 0 |  |  |  |  | 0 |  |  |  |  | 0 |  |  |  |  | 0 |  |  |  |  | 0
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

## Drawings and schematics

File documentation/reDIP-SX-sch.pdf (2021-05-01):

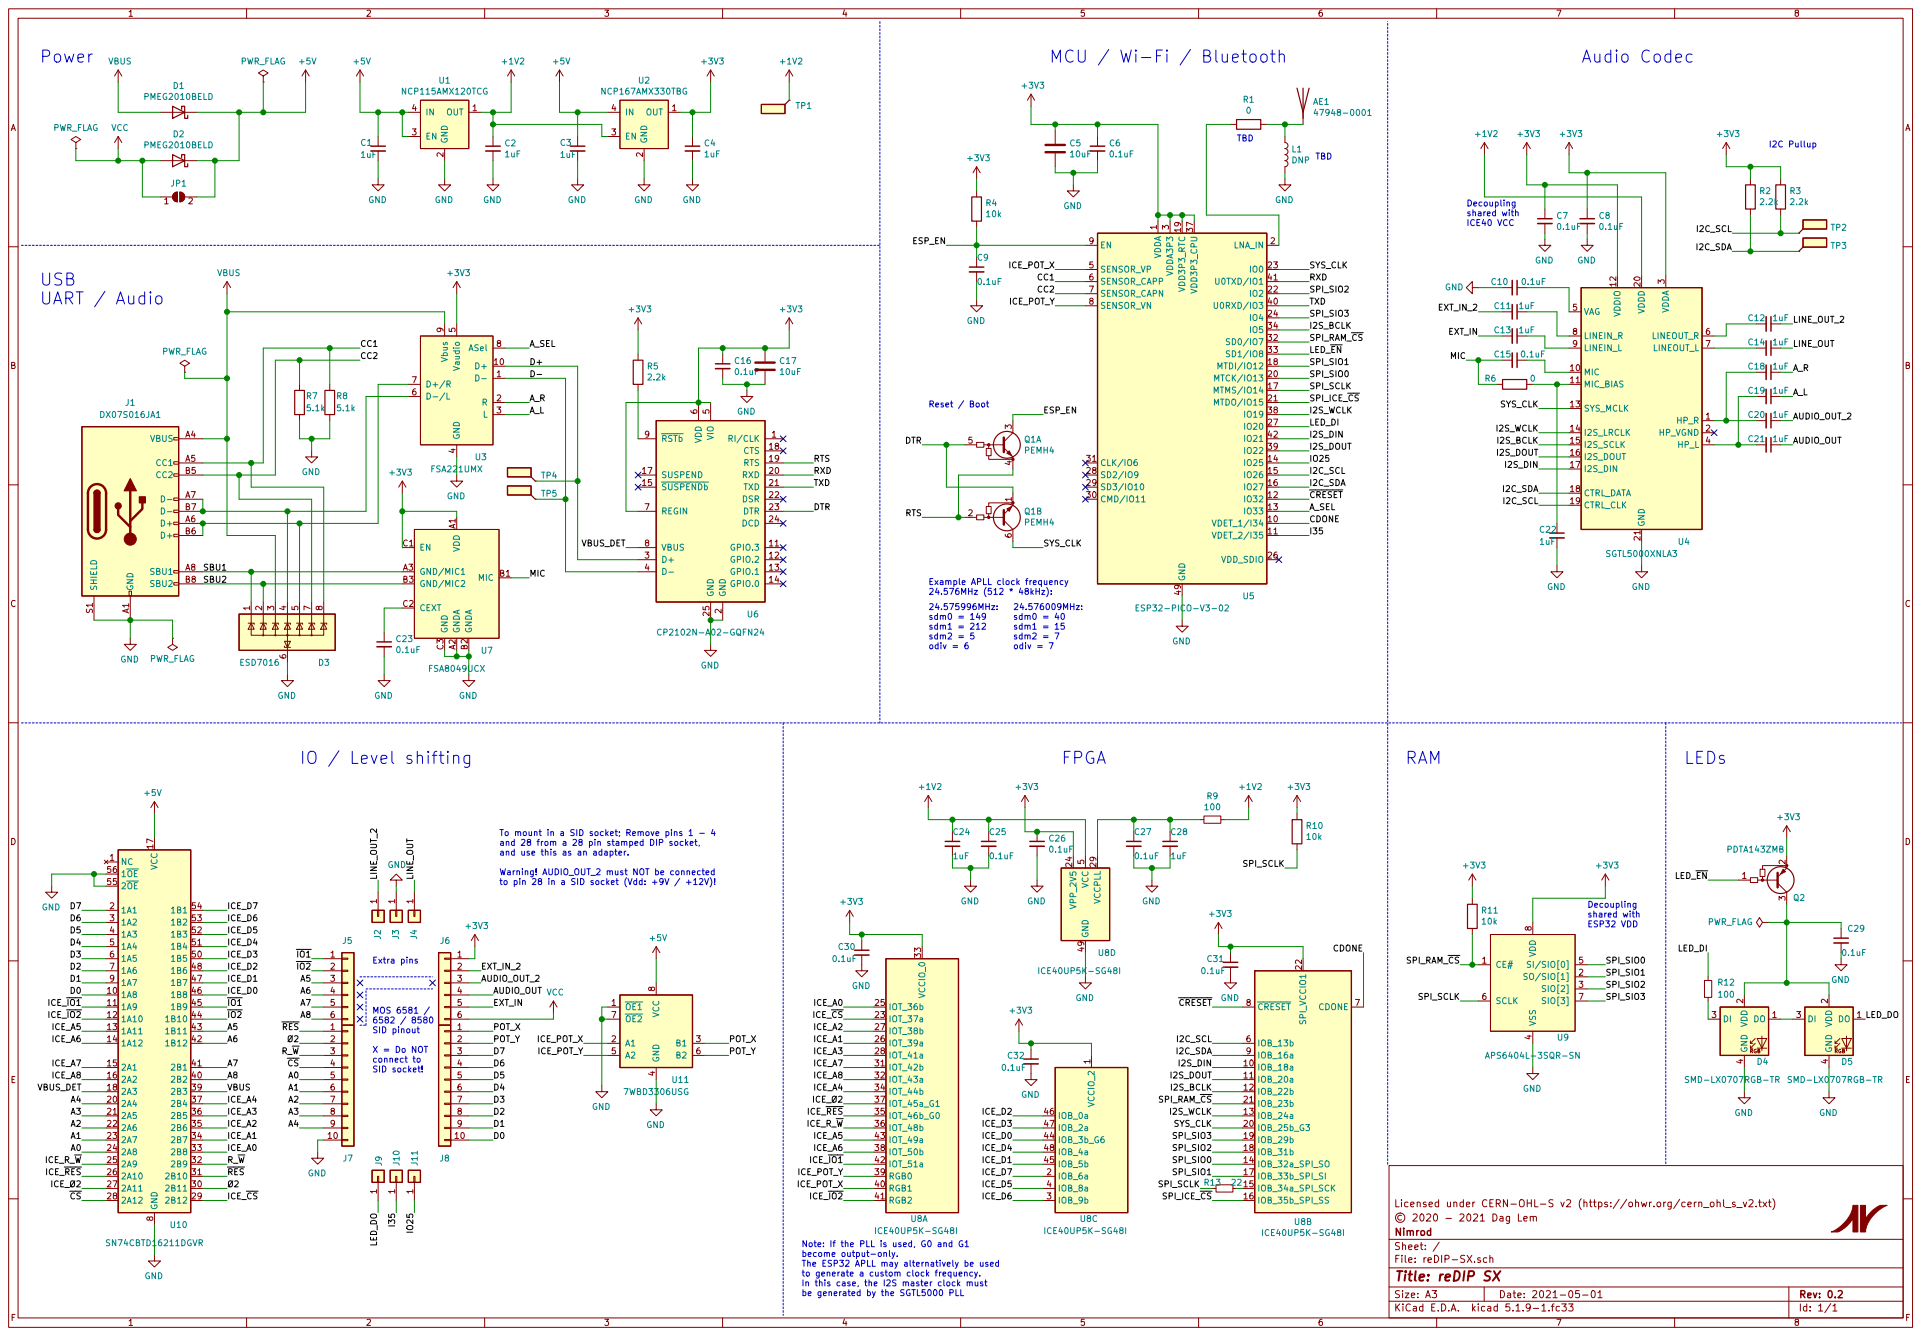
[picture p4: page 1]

2 RXD 20 TXD 21 DSR 22 DTR 23 DCD 24 GND 25 D+ 3 D- 4 VIO

RXD
TXD
odiv = 6 Note: If the PLL is used, G0 and G1

To mount in a SID socket; Remove pins 1 - 4
and 28 from a 28 pin stamped DIP socket,
and use this as an adapter.

Warning! AUDIO_OUT_2 must NOT be connected
to pin 28 in a SID socket (Vdd: +9V / +12V)!

4 SI/SIO[0] 5 SCLK 6 SIO[3] 7 VDD

MOS 6581 / 6582 / 8580 SID pinout X = Do NOT

Licensed under CERN-OHL-S v2 (https://ohwr.org/cern_ohl_s_v2.txt)
File: reDIP-SX.sch Sheet: / Nimrod © 2020 - 2021 Dag Lem

become output-only.
The ESP32 APLL may alternatively be used
to generate a custom clock frequency.
In this case, the I2S master clock must be generated by the SGTL5000 PLL

Id: 1/1 Title: reDIP SX

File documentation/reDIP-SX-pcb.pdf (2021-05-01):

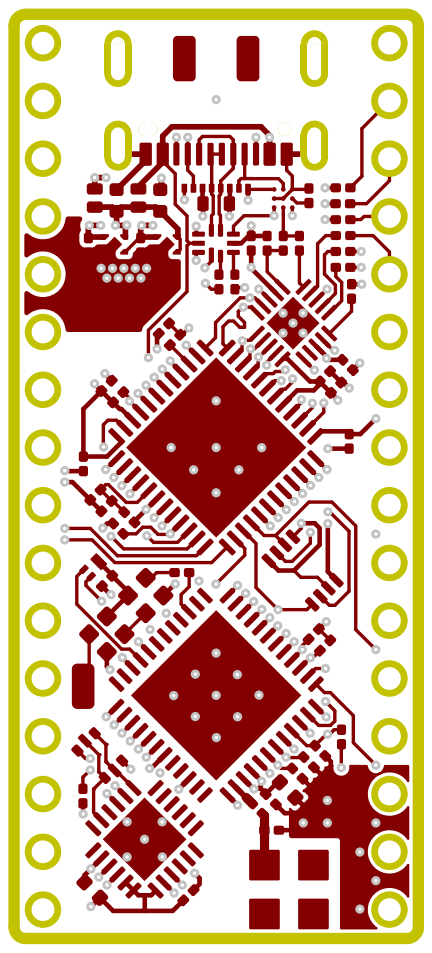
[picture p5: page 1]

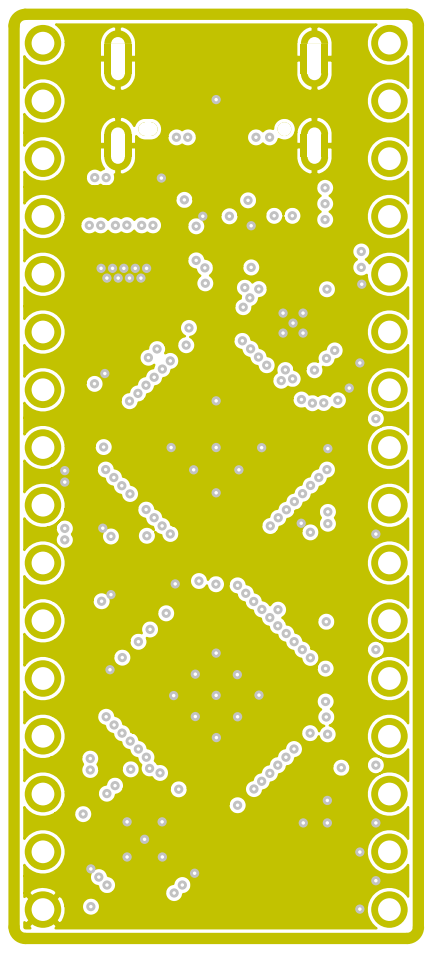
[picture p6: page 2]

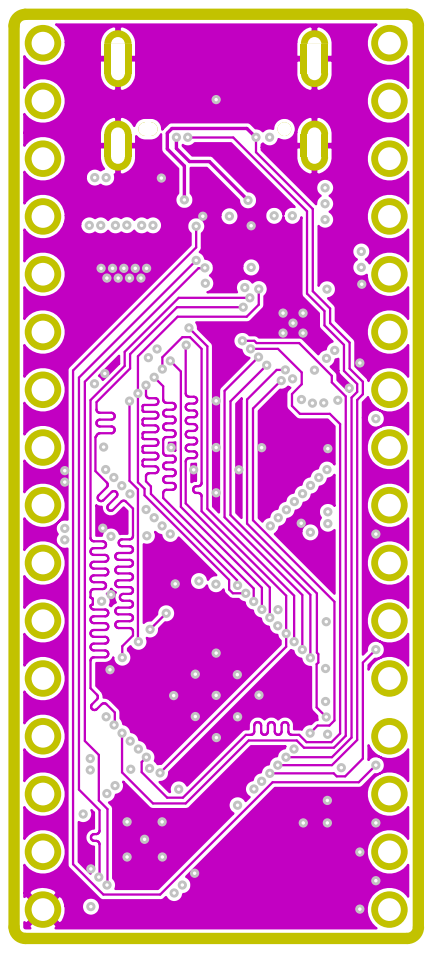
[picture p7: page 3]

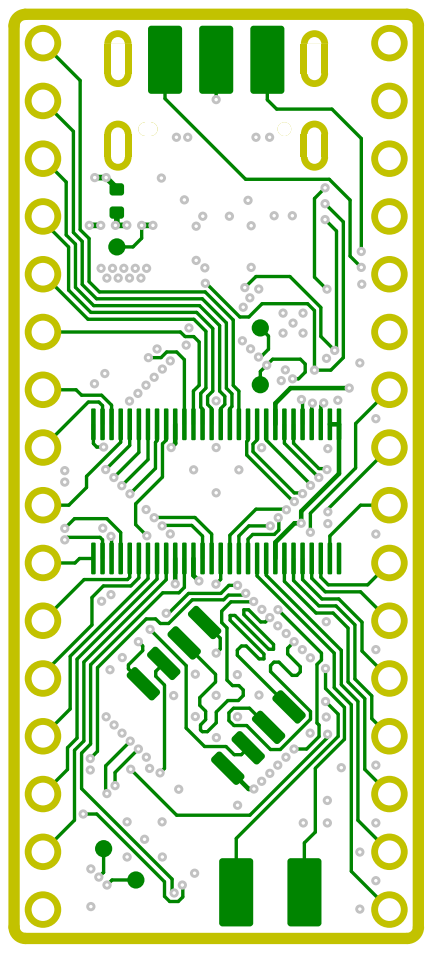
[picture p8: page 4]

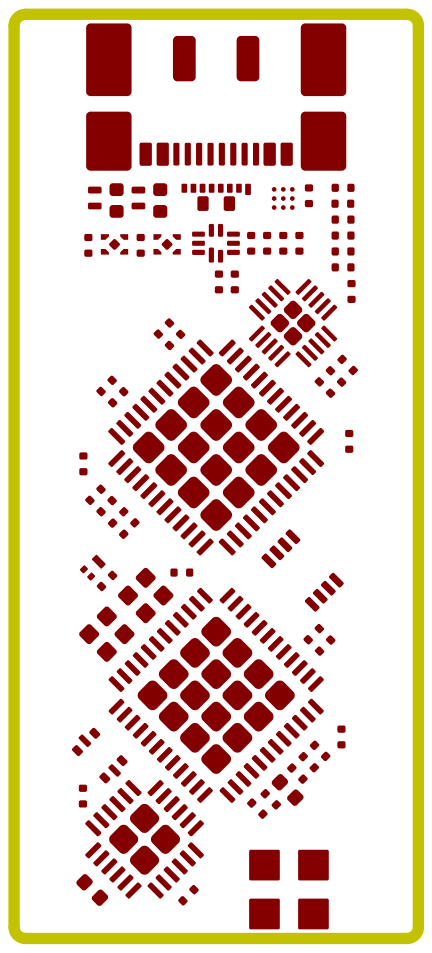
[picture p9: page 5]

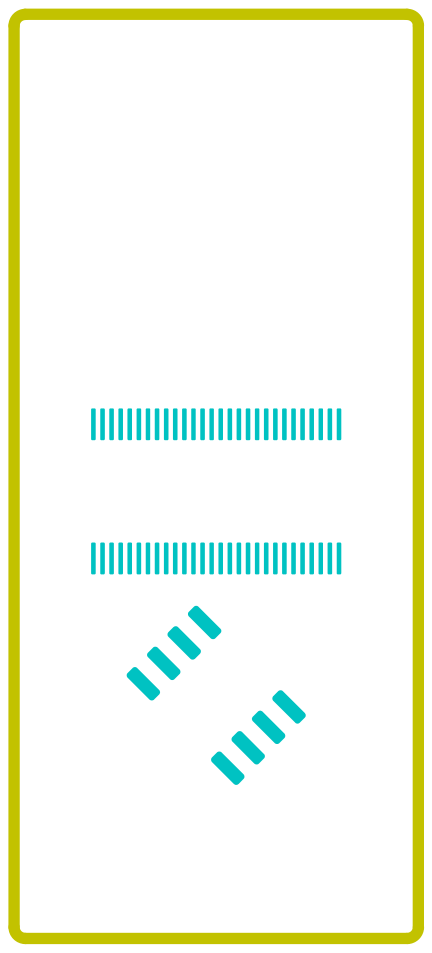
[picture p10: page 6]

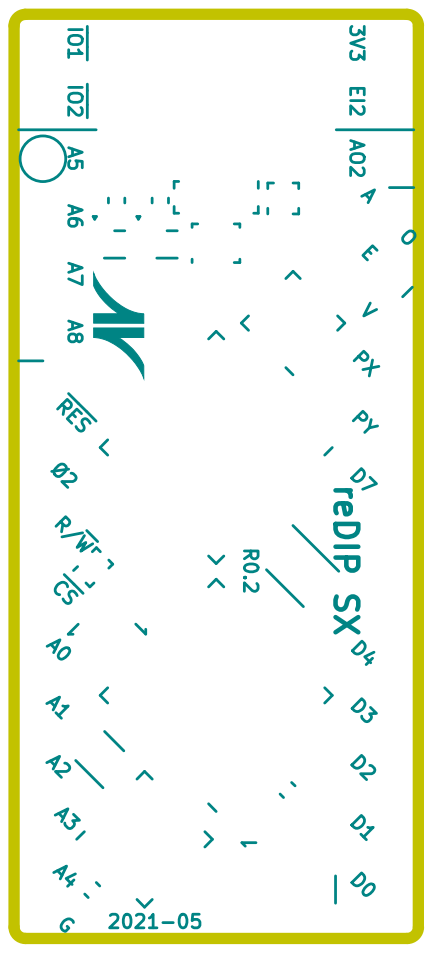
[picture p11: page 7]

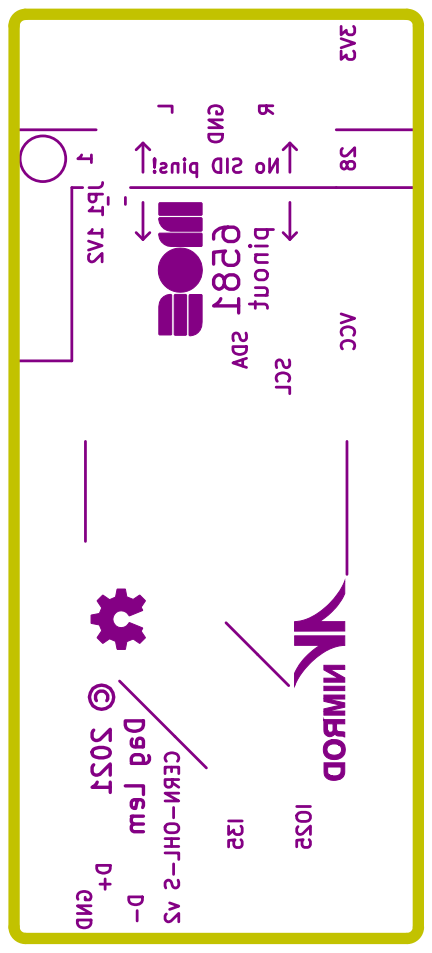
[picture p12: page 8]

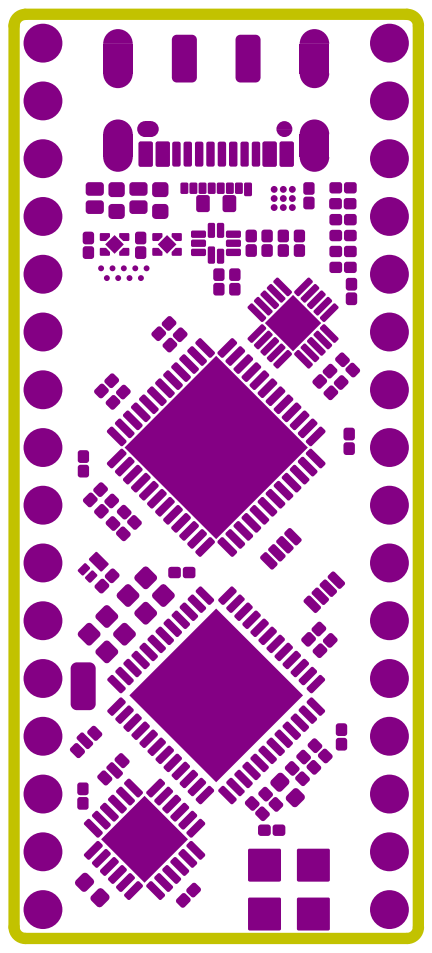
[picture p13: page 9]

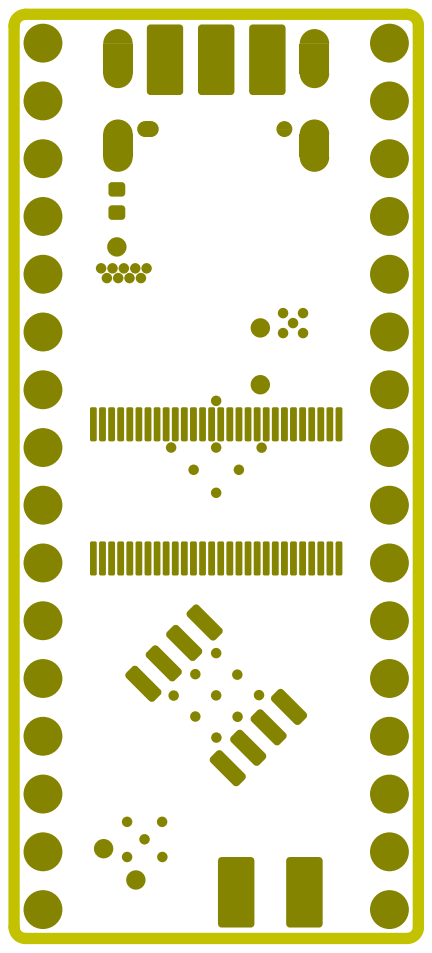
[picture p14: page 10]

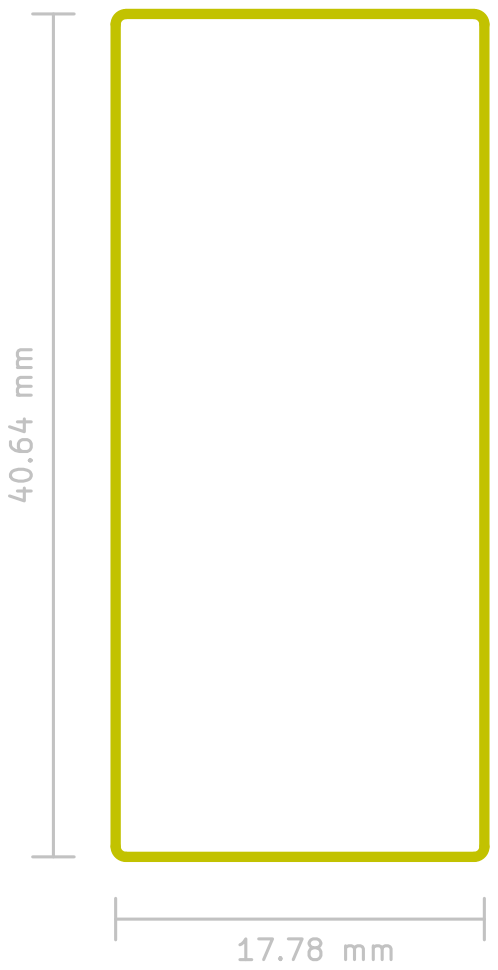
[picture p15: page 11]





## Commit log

2020-12-31 Usability and manufacturability improvements
    * Swapped pins for 3V3 and AO2
    * Replaced 0.35mm pitch BGA LDOs with larger pitch parts, improved layout
    * Removed IO2 pullup
    * Added solder pad for RGB LED strip
    * Increased solder mask clearance
    * Updated silk screen
    [reDIP-sx-BOM.xlsx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]
2021-01-08 A few small improvements
    * Added SPI SCLK source termination for iCE40UP5K
    * Changed R11 to 100Ω
    * Changed C27 to 0.1µF
    * Replaced a few capacitors with more readily available parts
    * Added datasheet URLs for all parts
    [reDIP-sx-BOM.xlsx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]
2021-01-08 Added missing update of board back image
2021-01-17 Usability and manufacturability improvements
    * Increased minimum via size (good luck on increasing it further!)
    * Corrected footprint rotation for D3 (IPC-7351)
    * Removed split in stencil apertures for pin-in-paste
    * Changed to shorter pin USB-C receptacle, yielding improved hole
    fill for partial pin penetration soldering
    * Adjustments to fab and silk screen layers
    * Added alternative ESP32 APLL configuration example to schematic
    [reDIP-sx-BOM.xlsx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]
2021-01-19 Renamed to reDIP SX
    [reDIP-SX-BOM.xlsx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]
2021-01-31 Adjusted TVSOP-56 footprint to match datasheet
    [reDIP-SX-B_Cu.gbr, reDIP-SX-B_Fab.gbr, reDIP-SX-B_Mask.gbr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]
2021-03-04 Various fixes
    * Added 10k pullup for SPI SCLK, following iCE40 Hardware Checklist
    * Increased through hole pad sizes for USB-C connector
    * Increased courtyard for TVSOP-56 footprint
    * Changed VCC to power symbol
    [reDIP-SX-BOM.xlsx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]
2021-04-18 Replaced non-stocked parts
    * Replaced 2 bit bus switch and 1.2V LDO with more readily available parts
    * Length matching for SPI_SIO3 (note that length matching is probably uncalled-for)
    [reDIP-SX-BOM.xlsx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]
2021-05-01 Various improvements
    * Improved decoupling and PLL power filtering,
    following suggestions by @smunaut for reDIP-SID
    * Capped component position resolution to 0.01mm
    * Routing cleanups
    * Note on the iCE40 PLL output-only-pin trap in the schematic
    * Added note on pin-in-paste for USB-C connector
    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
    [bom.csv, reDIP-SX-BOM.xlsx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]
